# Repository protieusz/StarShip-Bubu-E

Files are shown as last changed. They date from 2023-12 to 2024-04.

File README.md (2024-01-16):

# StarShip-Bubu-E
Upgraded StarShip Bubu-E. Solo trackball with PER56 encoder, 34mm trackball & 5 keys

This project is made possible by PCBWay.
If you ever need a PCB prototype, PCBWay is your go to service. They have fast PCBA turn around and customer service is top notch. Any issues with your files, they reached out to your before doing anything. Thanks, PCBWay!

Integrated PMW3360 sensor to the main pcb that has integrated RP2040 and RGBs.  Updated and refined case with bolts and screws so no need to hot glue or super glue the case. Looks better. No need to handwire to integrate the OmegaSupreme to the main pcb.

Full Production Pics: Jan 16, 2024
































Preview Renders:

Screenshot 2023-12-09 at 9 11 48 PM
Screenshot 2023-12-09 at 9 11 35 PM
Screenshot 2023-12-09 at 9 11 15 PM
Screenshot 2023-12-09 at 9 11 06 PM
Screenshot 2023-12-09 at 9 10 50 PM
Screenshot 2023-12-09 at 9 10 18 PM

# License

</a></p>

You are free to:

Share — copy and redistribute the material in any medium or format

Adapt — remix, transform, and build upon the material

The licensor cannot revoke these freedoms as long as you follow the license terms.
Under the following terms:

Attribution — You must give appropriate credit, provide a link to the license, and indicate if changes were made. You may do so in any reasonable manner, but not in any way that suggests the licensor endorses you or your use.

NonCommercial — You may not use the material for commercial purposes.

ShareAlike — If you remix, transform, or build upon the material, you must distribute your contributions under the same license as the original.

No additional restrictions — You may not apply legal terms or technological measures that legally restrict others from doing anything the license permits.

StarShip-Bubu-E by ProtieusKeebs is licensed under [CC BY-NC-SA 4.0](https://creativecommons.org/licenses/by-nc-sa/4.0/?ref=chooser-v1)

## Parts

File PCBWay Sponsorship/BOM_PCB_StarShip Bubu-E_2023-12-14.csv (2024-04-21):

ID | Name | Designator | Footprint | Quantity | Manufacturer Part | Manufacturer | Supplier | Supplier Part | Price | link
1 | SK6812MINI-E_C5149201 | U28,U29,U25,U26,U13,U14,U10,U11,U12,U15,U16,U17,U18,U19,U20,U21,U22,U23,U24,U27,U30,U31 | LED-SMD_L3.2-W2.8-TR | 22 | SK6812MINI-E | 欧思科光电 | LCSC | C5149201 | 0.124 | https://lcsc.com/eda_search?q=C5149201&%26type=1&ref=editor
2 | NO | +3V3,+5V,GND1 | PIN 1-PIN | 3
3 | 1uF | C1,C2,C5,C6,C9 | C0402 | 5 | CL05A105KA5NQNC | SAMSUNG(三星) | LCSC | C52923 | 0.004 | https://item.szlcsc.com/15869.html
4 | 22pF | C3,C4 | C0402 | 2 | 0402CG220J500NT | FH(风华) | LCSC | C1555 | 0.001 | https://item.szlcsc.com/15869.html
5 | 100nF | C7,C10,C11,C12,C13,C14,C15,C16 | C0402 | 8 | CL05B104KO5NNNC | SAMSUNG(三星) | LCSC | C1525 | 0.001 | https://item.szlcsc.com/15869.html
6 | 10uF | C8 | C0402 | 1 | CL05A106MQ5NUNC | SAMSUNG(三星) | LCSC | C15525 | 0.005 | https://item.szlcsc.com/15869.html
7 | 4.7uF | C17,C19,C20 | C0402 | 3 | CL05A475MP5NRNC | SAMSUNG(三星) | LCSC | C23733 | 0.006 | https://lcsc.com/eda_search?q=C23733&%26type=1&ref=editor
8 | 100nF | C18 | C0402 | 1 | CL05B104KB54PNC | SAMSUNG(三星) | LCSC | C307331 | 0.006 | https://lcsc.com/eda_search?q=C307331&%26type=1&ref=editor
9 | PRTR5V0U2X,215 | D11 | SOT-143_L2.9-W1.3-P1.92-LS2.3-BR | 1 | PRTR5V0U2X,215 | Nexperia(安世) | LCSC | C12333 | 0.147 | https://item.szlcsc.com/280548.html
10 | BSMD0805-020-15V | F1 | F0805 | 1 | BSMD0805-020-15V | BHFUSE(佰宏) | LCSC | C883103 | 0.045 | https://item.szlcsc.com/343298.html
11 | 5.1kΩ | R1,R2,R3,R4,R5 | R0402 | 5 | 0402WGF5101TCE | UNI-ROYAL(厚声) | LCSC | C25905 | 0.001 | https://item.szlcsc.com/323315.html
12 | 1kΩ | R6,R7 | R0402 | 2 | 0402WGF1001TCE | UNI-ROYAL(厚声) | LCSC | C11702 | 0.001 | https://item.szlcsc.com/323315.html
13 | 27Ω | R8,R9 | R0402 | 2 | 0402WGF270JTCE | UNI-ROYAL(厚声) | LCSC | C25100 | 0.001 | https://item.szlcsc.com/323315.html
14 | 10kΩ | R10,R12,R13 | R0402 | 3 | 0402WGF1002TCE | UNI-ROYAL(厚声) | LCSC | C25744 | 0.001 | https://lcsc.com/eda_search?q=C25744&%26type=1&ref=editor
15 | 39Ω | R11 | R0402 | 1 | 0402WGJ0390TCE | UNI-ROYAL(厚声) | LCSC | C25164 |  | https://lcsc.com/eda_search?q=C25164&%26type=1&ref=editor
16 | 15kΩ | R14 | R0402 | 1 | 0402WGF1502TCE | UNI-ROYAL(厚声) | LCSC | C25756 | 0.001 | https://lcsc.com/eda_search?q=C25756&%26type=1&ref=editor
17 | RESET | U1 | RESET SWITCH | 1
18 | BOOT | U2 | RESET SWITCH | 1
19 | W25Q128JVSIQTR | U3 | SOIC-8_L5.3-W5.3-P1.27-LS8.0-BL | 1 | W25Q128JVSIQ | WINBOND(华邦) | LCSC | C97521 | 0.611 | https://item.szlcsc.com/63461.html
20 | RP2040 | U4 | LQFN-56_L7.0-W7.0-P0.4-EP | 1 | RP2040 | Raspberry Pi(树莓派) | LCSC | C2040 | 1.076 | https://atta.szlcsc.com/upload/public/pdf/source/20210621/C2040_96F425825606B7957D87DD32E2512CA9.pdf
21 | XC6206P332MR | U5 | SOT-23-3_L2.9-W1.6-P1.90-LS2.8-BR | 1 | XC6206P332MR | TOREX(特瑞仕) | LCSC | C5446 | 0.106 | https://item.szlcsc.com/14454.html
22 | SN74LVC1T45QDCKRQ1 | U6 | SC-70-6_L2.0-W1.3-P0.65-LS2.1-BR | 1 | SN74LVC1T45QDCKRQ1 | TI(德州仪器) | LCSC | C139353 | 0.382 | https://lcsc.com/eda_search?q=C139353&%26type=1&ref=editor
23 | PMW3360DM-T2QU | U7 | PMW3360DM-T2QU.PACK | 1 | PMW3360DM-T2QU |  |  |  |  | http://www.pixart.com/upload/PMS0058-PMW3360DM-T2QU-NNDS-R1.30-06042016_20160902201411.pdf
24 | AP2127K-ADJTRG1 | U8 | SOT-23-5_L3.0-W1.7-P0.95-LS2.8-BR | 1 | AP2127K-ADJTRG1 | DIODES(美台) | LCSC | C96343 | 0.059 | https://lcsc.com/eda_search?q=C96343&%26type=1&ref=editor
25 | TYPE-C-31-M-12 | USBC1 | USB-C_SMD-TYPE-C-31-M-12 | 1 | TYPE-C-31-M-12 | 韩国韩荣 | LCSC | C165948 | 0.159 | https://so.szlcsc.com/global.html?c=&k=C165948
26 | 12MHz | X1 | OSC-SMD_4P-L3.2-W2.5-BL | 1 | X322512MSB4SI | YXC(扬兴晶振) | LCSC | C9002 | 0.059 | https://item.szlcsc.com/15866.html
27 | SM4007PL | D100,D101,D102,D000,D001 | SOD-123F_L2.8-W1.8-LS3.7-RD | 5 | SM4007PL | MDD | LCSC | C64898 | 0.007 | https://item.szlcsc.com/60254.html
28 | NO | U100,U101 | MT_HOLE-3MM | 2
29 | PER561-P115-N0015 | IC1 | PER561P115N0015 | 1
30 | Switch | K100,K101,K102,K000,K001 | CHERRY_MX_100_MILLMAX | 5

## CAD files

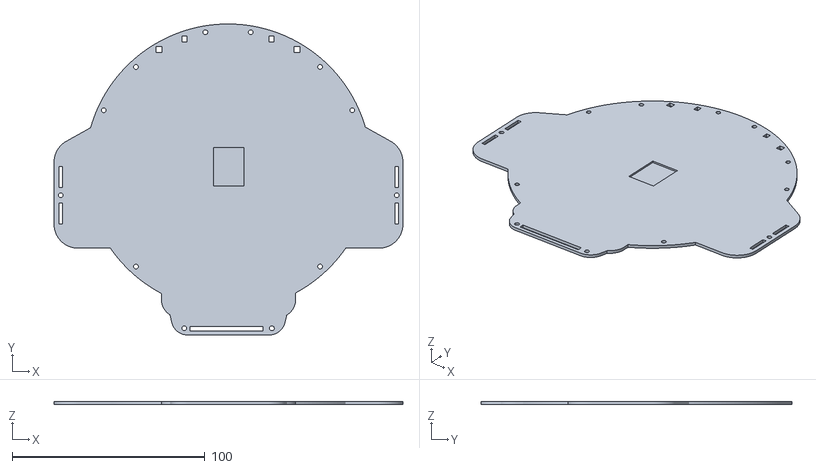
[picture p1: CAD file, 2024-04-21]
stl/Bubu2.0BottomCase.stl
181.0 x 161.3 x 1.60

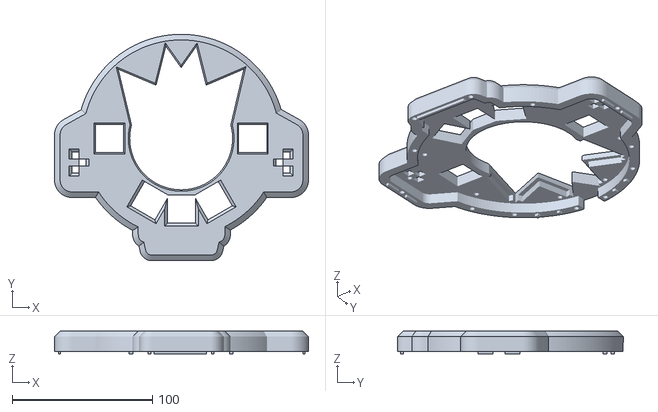
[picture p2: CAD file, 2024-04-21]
stl/Bubu2.0TopCase.stl
181.0 x 161.3 x 16.2

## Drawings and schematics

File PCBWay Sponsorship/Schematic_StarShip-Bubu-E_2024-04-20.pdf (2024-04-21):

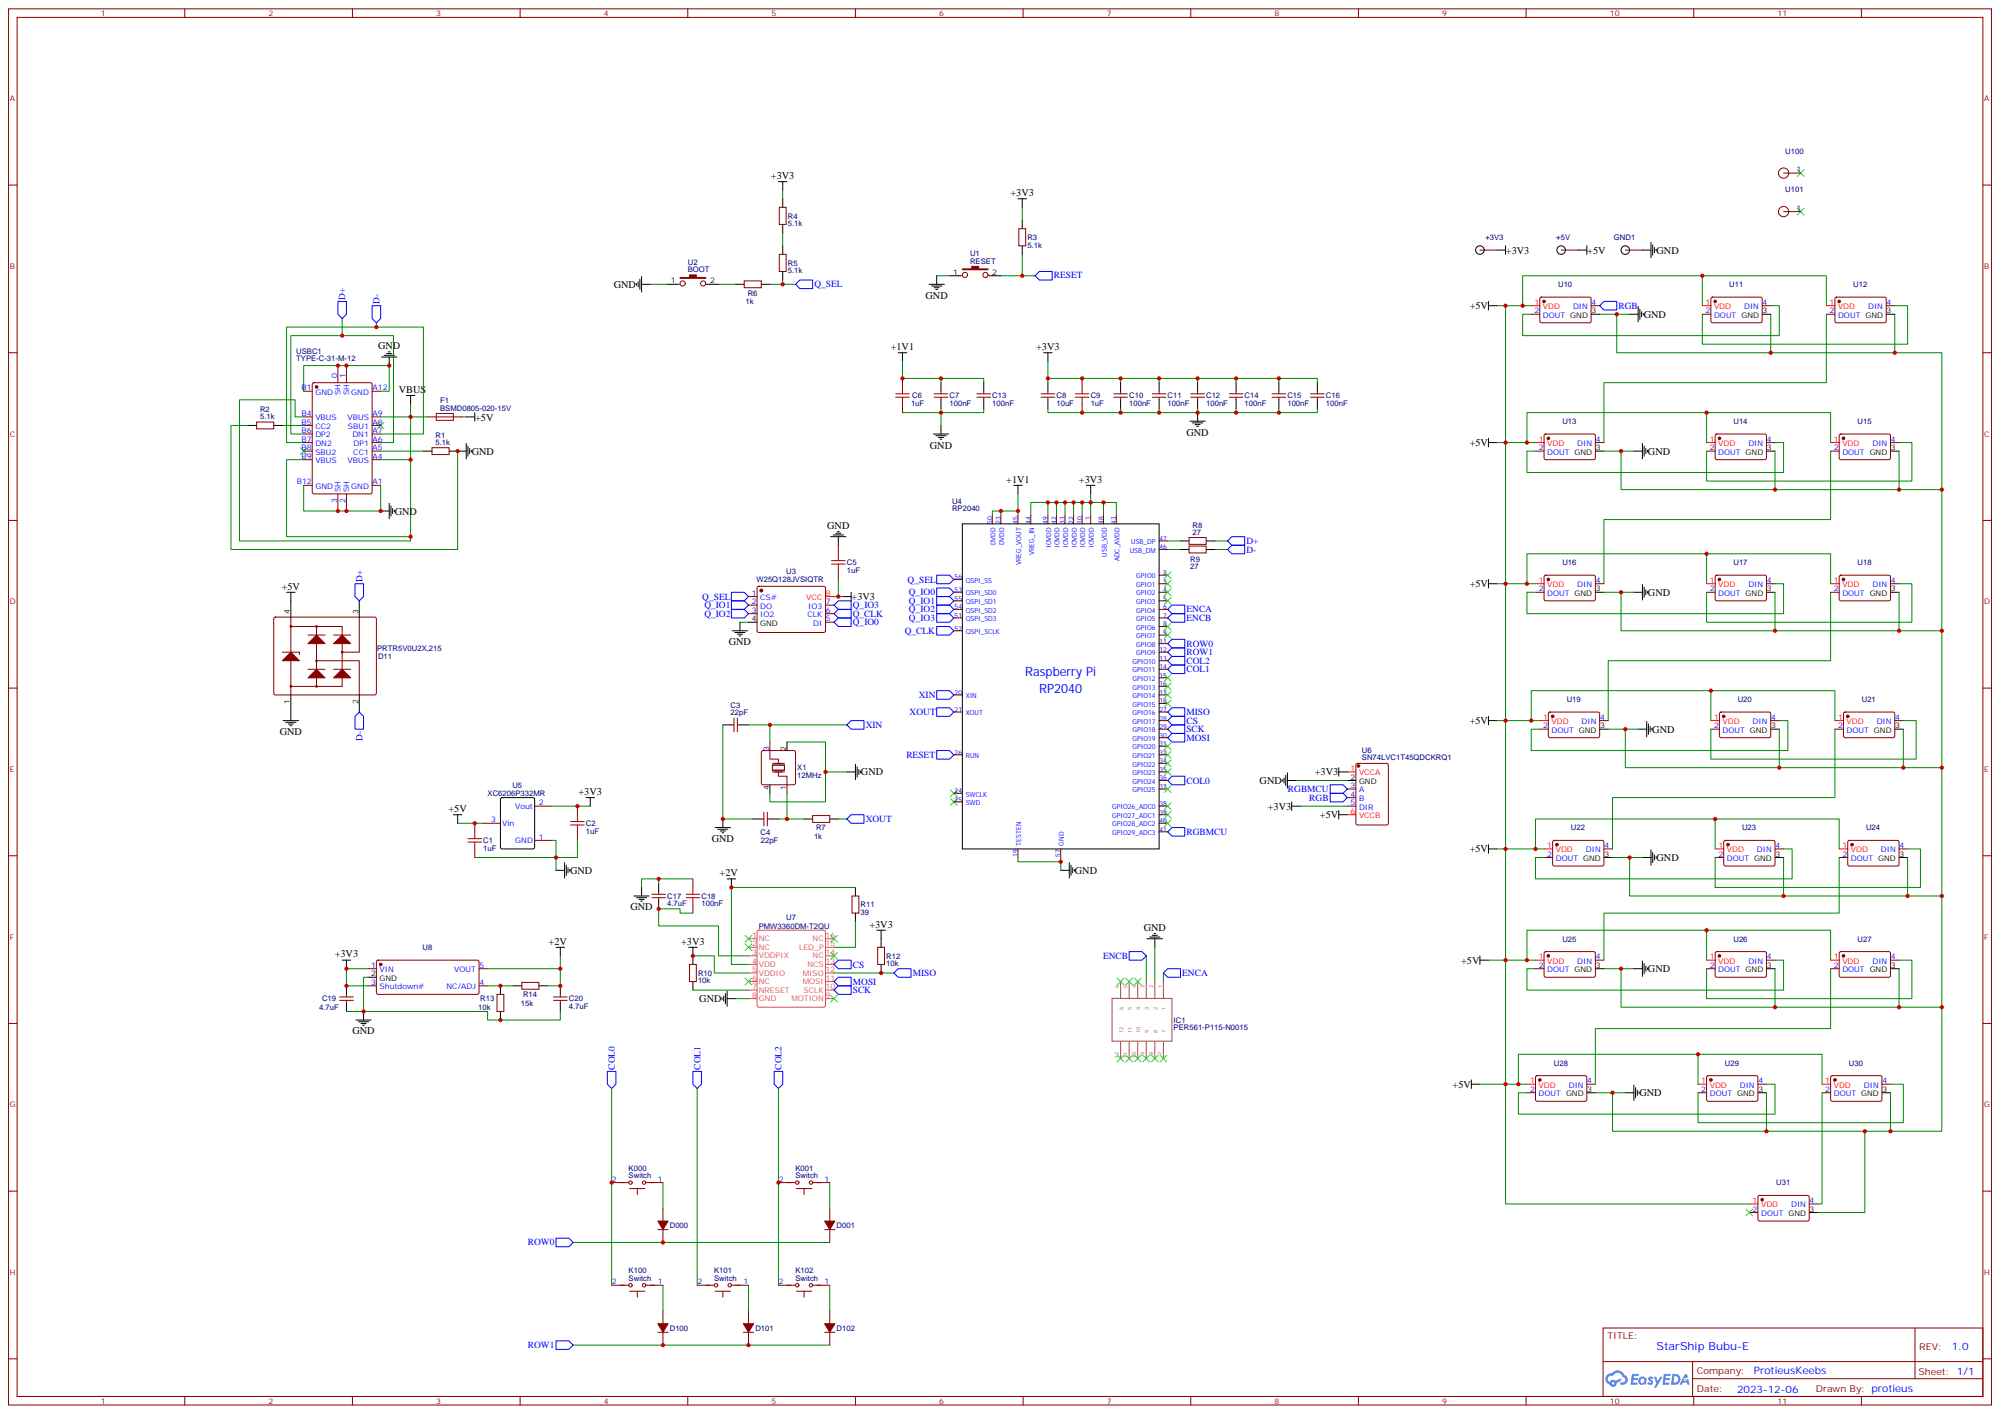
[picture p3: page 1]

SCLK 10 MOSI 11 MISO 12 NCS 13 NC 14 LED_P 15 NC 16

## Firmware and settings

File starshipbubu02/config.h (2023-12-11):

// Copyright 2023 aki27 (@aki27kbd)
// SPDX-License-Identifier: GPL-2.0-or-later

#pragma once

//#define VIAL_KEYBOARD_UID {0xC4, 0x18, 0xCC, 0x6D, 0x1C, 0x16, 0x5B, 0x8D}
//#define VIAL_UNLOCK_COMBO_ROWS {0, 0}
//#define VIAL_UNLOCK_COMBO_COLS {1, 11}

/* VIA */
//#define DYNAMIC_KEYMAP_LAYER_COUNT 8


/* key matrix size */
//#define MATRIX_COLS 13
//#define MATRIX_ROWS 4


/* tapping term */
// #define TAPPING_FORCE_HOLD
//#define TAPPING_TERM 200
// #define IGNORE_MOD_TAP_INTERRUPT

#define RP2040_BOOTLOADER_DOUBLE_TAP_RESET // Activates the double-tap behavior
#define RP2040_BOOTLOADER_DOUBLE_TAP_RESET_TIMEOUT 200U // Timeout window in ms in which the double tap can occur.

#ifdef COMBO_ENABLE
#    define COMBO_COUNT 6
#    define COMBO_TERM 200
#endif

/* Encoder */
//#define ENCODERS_PAD_A { GP11 }
//#define ENCODERS_PAD_B { GP12 }
//#define ENCODER_RESOLUTION 4

/* Matrix*/
//#define MATRIX_COL_PINS { GP25, GP24, GP23, GP22, GP21, GP26, GP27, GP20, GP19, GP18, GP17, GP16, GP13 }
//#define MATRIX_ROW_PINS { GP28, GP10, GP14, GP15 }

/* COL2ROW, ROW2COL */
//#define DIODE_DIRECTION COL2ROW


/* Set 0 if debouncing isn't needed */
//#define DEBOUNCE 5


/* Mechanical locking support. Use KC_LCAP, KC_LNUM or KC_LSCR instead in keymap (Very Important for Scroll Lock!!!) */
#undef LOCKING_SUPPORT_ENABLE
/* Locking resynchronize hack */
#undef LOCKING_RESYNC_ENABLE


/* RGB LED */
//#define WS2812_PIO_USE_PIO1
#define WS2812_DI_PIN GP29

#ifdef RGBLIGHT_ENABLE
    #define RGBLED_NUM 3
    #define RGBLIGHT_LIMIT_VAL 255
    #define RGBLIGHT_HUE_STEP 10
    #define RGBLIGHT_SAT_STEP 17
    #define RGBLIGHT_VAL_STEP 17
    //#define RGBLIGHT_SLEEP  /* If defined, the RGB lighting will be switched off when the host goes to sleep */

    // #define RGBLIGHT_ANIMATIONS
    #define RGBLIGHT_EFFECT_BREATHING
    #define RGBLIGHT_EFFECT_RAINBOW_MOOD
    #define RGBLIGHT_EFFECT_RAINBOW_SWIRL
    #define RGBLIGHT_EFFECT_SNAKE
    #define RGBLIGHT_EFFECT_KNIGHT
    #define RGBLIGHT_EFFECT_CHRISTMAS
    #define RGBLIGHT_EFFECT_STATIC_GRADIENT
    #define RGBLIGHT_EFFECT_TWINKLE
    #define RGBLIGHT_EFFECT_ALTERNATING
#endif


/* Trackball */

#ifdef POINTING_DEVICE_ENABLE

//#    undef RP_SPI_USE_SPI0
//#    define RP_SPI_USE_SPI0 TRUE
//#    undef RP_SPI_USE_SPI1
//#    define RP_SPI_USE_SPI1 FALSE
#    define SPI_DRIVER SPID0

//#    define SPI_SCK_PIN GP22 //6
//#    define SPI_MISO_PIN GP24 //4
//#    define SPI_MOSI_PIN GP23 //7
#    define SPI_SCK_PIN GP18
#    define SPI_MISO_PIN GP16
#    define SPI_MOSI_PIN GP19

#endif


#ifndef PMW33XX_CS_PIN
#    define PMW33XX_CS_PIN GP17
#endif
#define POINTING_DEVICE_INVERT_X
#define POINTING_DEVICE_INVERT_Y
//#define ROTATIONAL_TRANSFORM_ANGLE 90
#define POINTING_DEVICE_ROTATION_180

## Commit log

2024-04-21 Gerber/BOM/Components Placement
    [BOM_PCB_StarShip Bubu-E_2023-12-14.csv, PickAndPlace_PCB_StarShip Bubu-E_2023-12-14.csv]
2024-04-21 Add pcb schematic

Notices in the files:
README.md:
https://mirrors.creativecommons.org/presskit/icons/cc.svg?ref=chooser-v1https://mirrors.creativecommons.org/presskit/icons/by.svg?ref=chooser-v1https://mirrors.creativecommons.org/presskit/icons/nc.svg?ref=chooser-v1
